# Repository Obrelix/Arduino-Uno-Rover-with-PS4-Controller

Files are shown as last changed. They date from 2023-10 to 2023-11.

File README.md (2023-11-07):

# Arduino Uno Rover with PS4 Controller

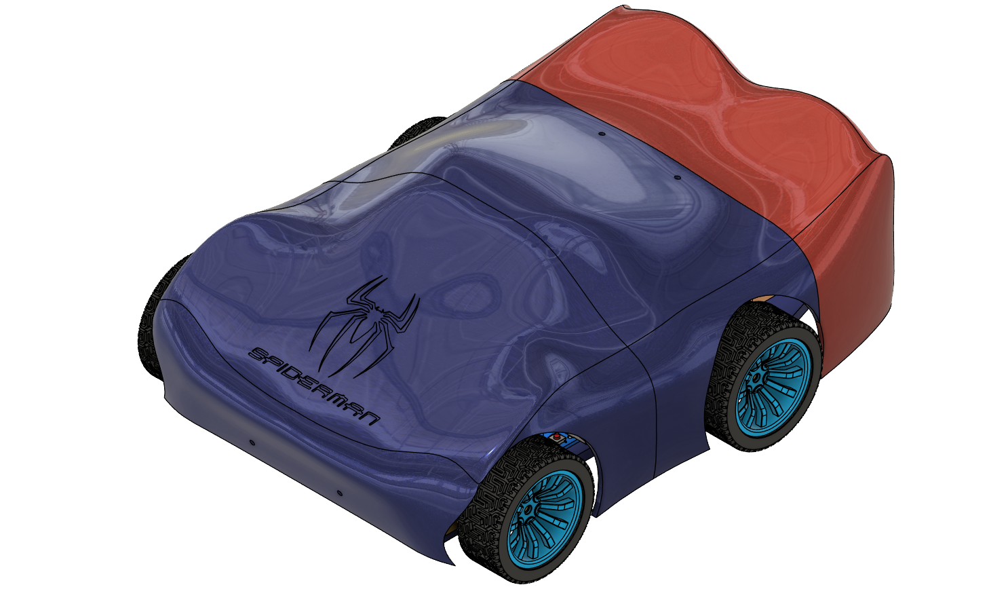
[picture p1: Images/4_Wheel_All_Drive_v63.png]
Rover Image


 Watch the video (https://youtu.be/d1QcqxO6J48)

This project showcases an Arduino Uno-based rover with a PS4 controller interface. The rover boasts four 65mm rubber wheels, driven by four JGB370-3530 brushed geared motors and controlled by dual L298N motor drivers. It runs on four 18650 Li-Ion batteries with a 4S BMS, ensuring ample power for all its electronic components for approximately 15-25 minutes on a single charge.

## Features

- **PS4 Controller Integration:** Control the rover via Bluetooth using a PS4 controller, enabled by the Arduino USB host shield and a Bluetooth dongle.  
- Support for various control **modes:**
  - **Car mode:** Control a car-like rover using joysticks.
  - **Car mode with triggers:** Control a car-like rover using triggers and the left joystick.
  - **Car mode with accelerometers:** Control a car-like rover using triggers for throttle and the accelerometer for steering.
  - **Funky car mode:** Control a unique car-like rover using the accelerometer for both throttle and steering.
  - **Tank mode:** Control a tank-like robot with separate control for each side using joysticks.
- **Turbo mode:** Activate turbo mode for max speed.
- **Speed mode:** Adjust the robot's speed on the fly. (doesn't apply to the turbo mode)
- **LED and Rumble feedback:** Indicate the current control mode and turbo mode using LED and rumble feedback on the PS4 controller.
- **3D-Printed Chassis:** The project includes 3D-printed chassis and shell models, designed with Fusion 360. These models are conveniently divided into parts for easier printing and assembly.

## Getting Started

To build and operate this project, follow these steps:

1. Assemble the rover chassis and shell using the 3D-printed parts provided in the [3D_Models](3D_Models/Printed_Parts) directory.

2. Connect the motors to the L298N motor drivers.

3. Ensure that the L298N motor drivers receive the correct power supply: raw voltage from the 4S BMS (>12V) and additional 5V voltage from a dc-to-dc step-down buck converter.

4. Set up the Arduino Uno with the required libraries and connect the Arduino USB host shield and Bluetooth dongle.

5. Upload the provided [Arduino sketch](AWD_PS4_RC/AWD_PS4_RC.ino) to the Arduino Uno.

6. Confirm that the Arduino Uno is powered with 12V from an individual dc-to-dc step-down buck converter.
   
7. Pair your PS4 controller with the Bluetooth dongle.
   
8. Power on the rover and start controlling it with your PS4 controller.   

## Usage

1. Control Modes:
   - Press the "Options" OR "Share" button to cycle through different control modes.
   - Control the robot based on the selected mode using the PS4 controller's buttons, joysticks, and triggers.

2. Turbo Mode:
   - Activate turbo mode by pressing specific button sequences on the controller (e.g., L1 + R1 + Triangle + Left).
   - Turbo mode increases the robot's speed.

3. Speed Mode:
   - Adjust the robot's speed by pressing the "Up" and "Down" buttons on the controller.

4. LED Feedback:
   - The LED on the PS4 controller provides feedback on the current control mode and turbo mode status.
     
## License

This project is licensed under the GNU GENERAL PUBLIC LICENSE - see the [LICENSE](https://github.com/Obrelix/Arduino-Uno-Rover-with-PS4-Controller/blob/main/LICENSE) file for details.

## Acknowledgments

- This project owes its existence to the contributions of the open-source Arduino community and the PS4BT library for Arduino.

- Special thanks to my collaborators, Kostas Vrailas and Thomas Vasiliou, who joined forces to create this project as a delightful gift for Kostas's young son.

Feel free to contribute, enhance, or customize this project as needed. If you have questions or feedback, please open an issue or get in touch with us.

Happy roving! 🚀

## Images

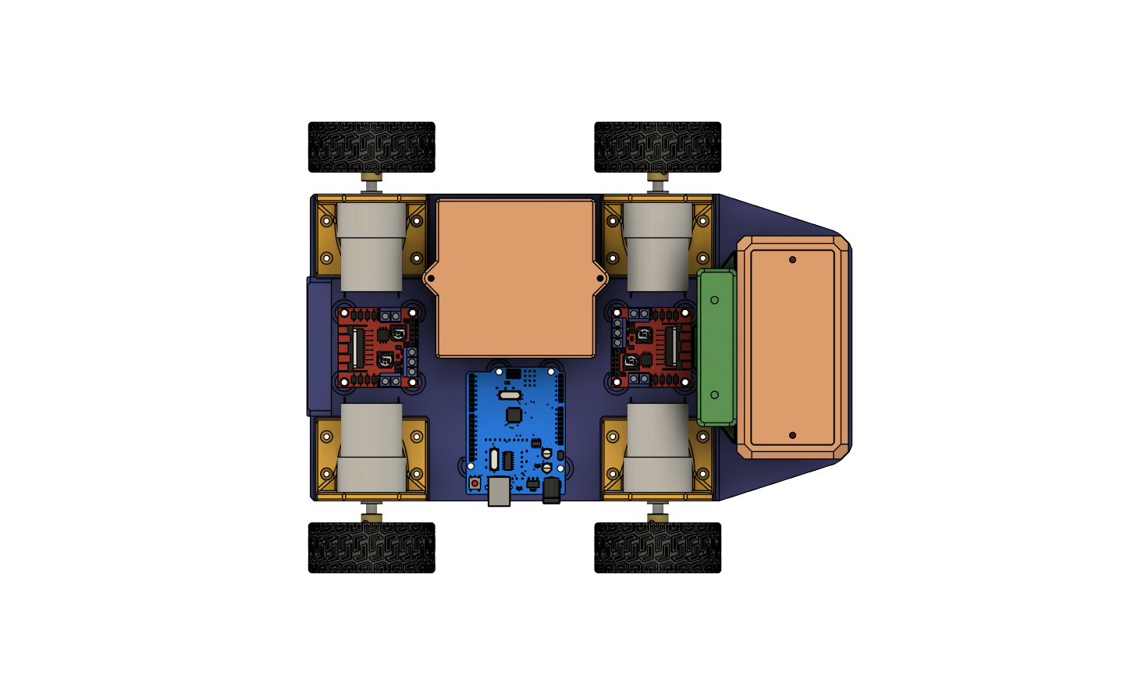
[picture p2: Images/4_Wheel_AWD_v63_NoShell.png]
Rover Image

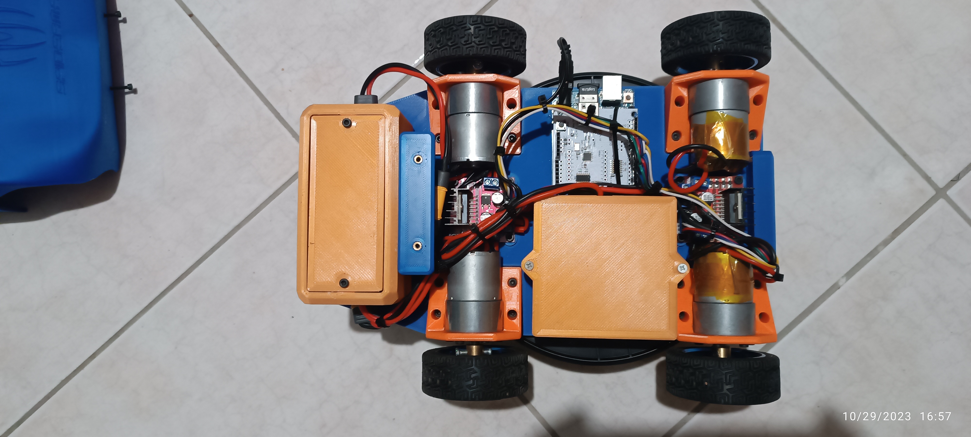
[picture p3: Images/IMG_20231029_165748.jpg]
Rover Image

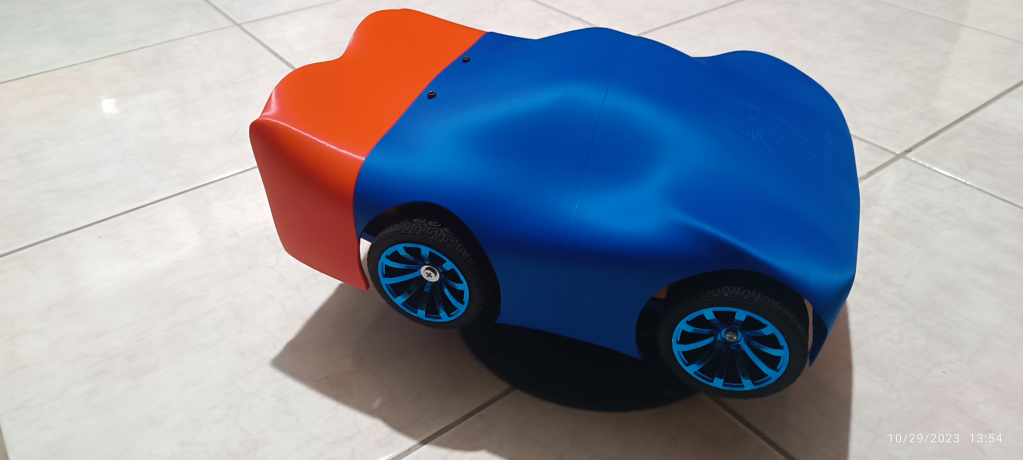
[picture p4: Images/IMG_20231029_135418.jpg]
Rover Image

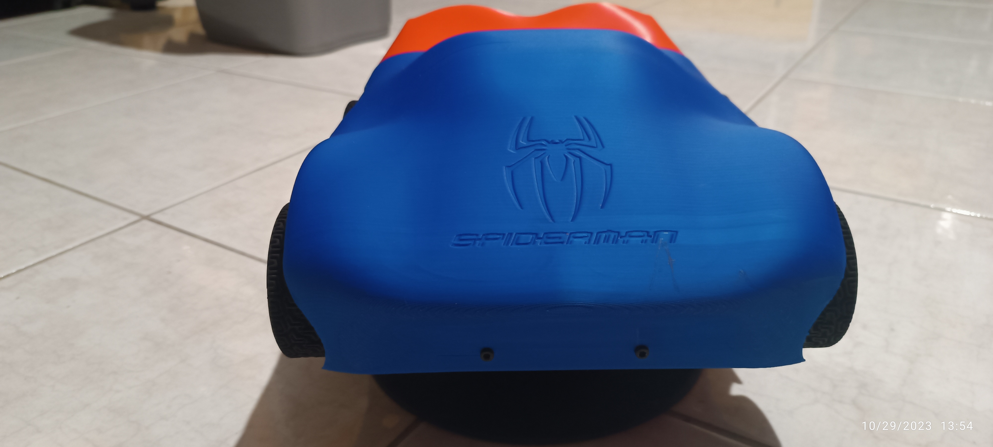
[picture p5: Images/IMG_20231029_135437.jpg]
Rover Image

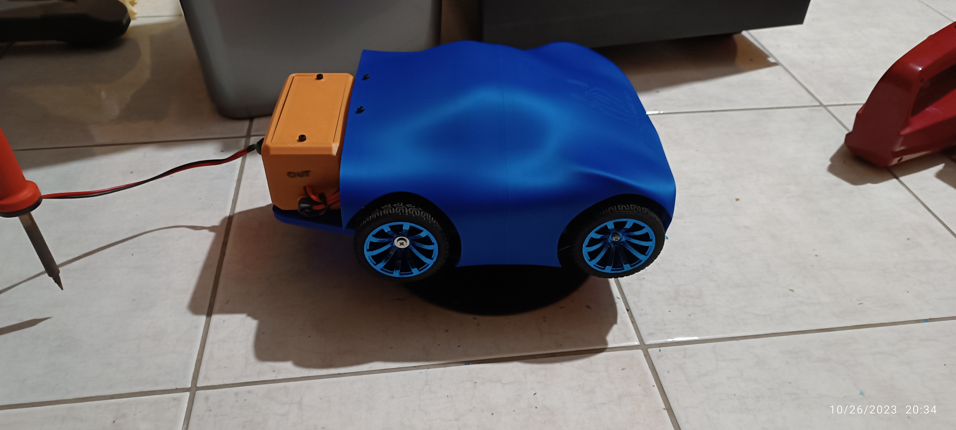
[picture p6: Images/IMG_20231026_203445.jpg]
Rover Image


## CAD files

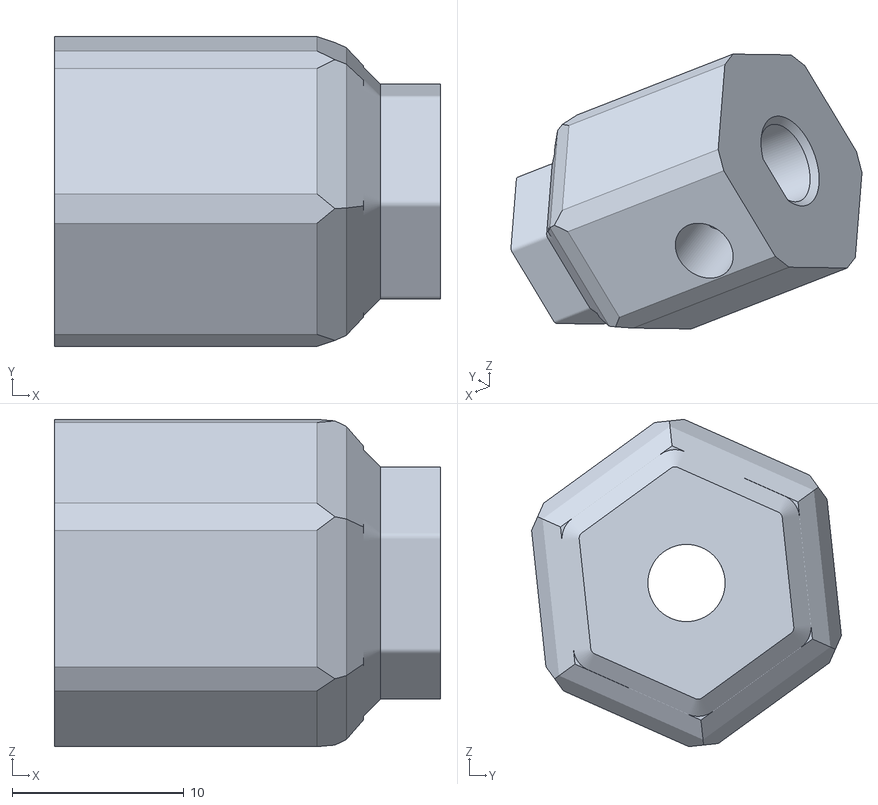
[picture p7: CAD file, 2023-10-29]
3D_Models/Printed_Parts/Wheel Adaptor x 4.stl
22.5 x 18.1 x 19.1

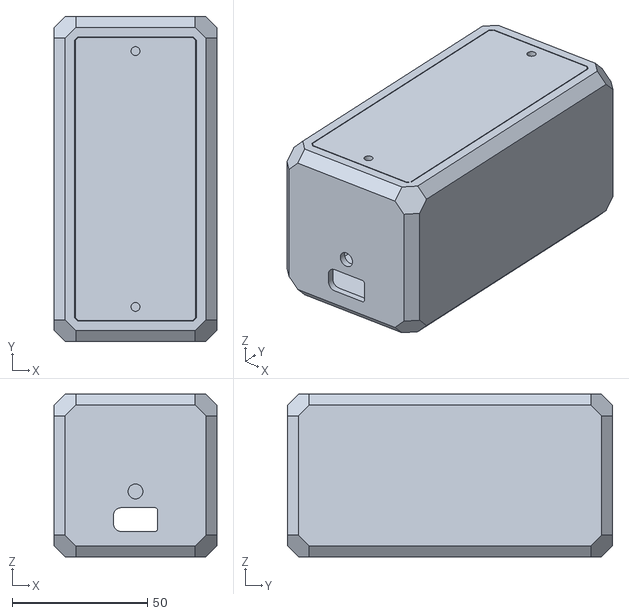
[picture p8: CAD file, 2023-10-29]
3D_Models/Printed_Parts/Power Box v4.stl
60.0 x 120.0 x 60.0

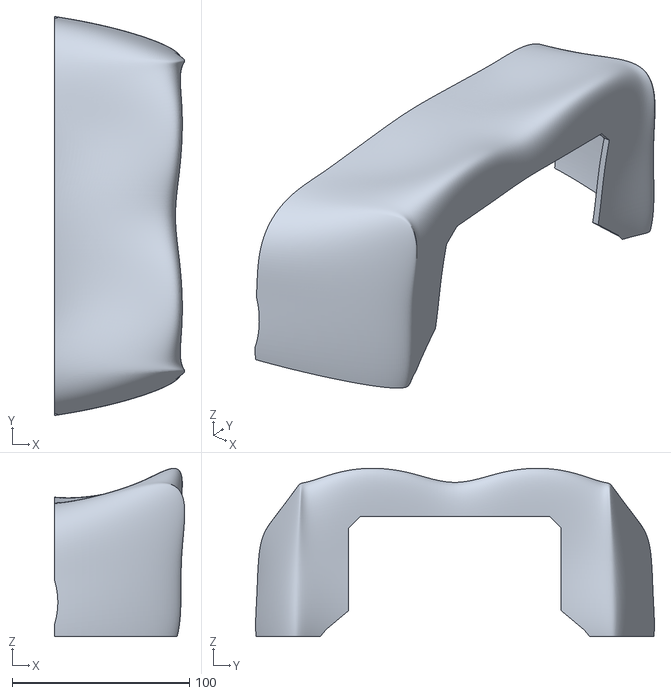
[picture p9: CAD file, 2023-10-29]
3D_Models/Printed_Parts/Shell Back.stl
73.6 x 225.1 x 95.0

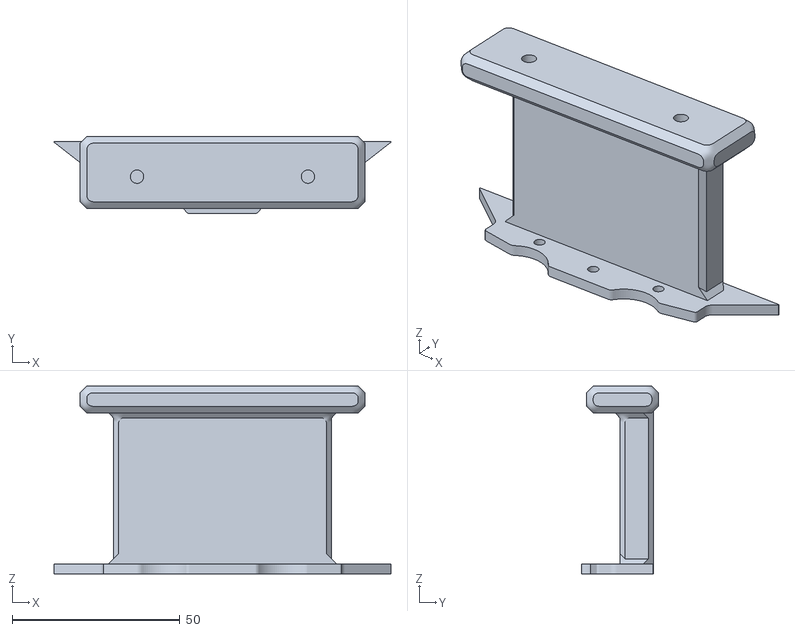
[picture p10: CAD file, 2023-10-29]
3D_Models/Printed_Parts/Rear Joint.stl
100.6 x 23.0 x 56.0

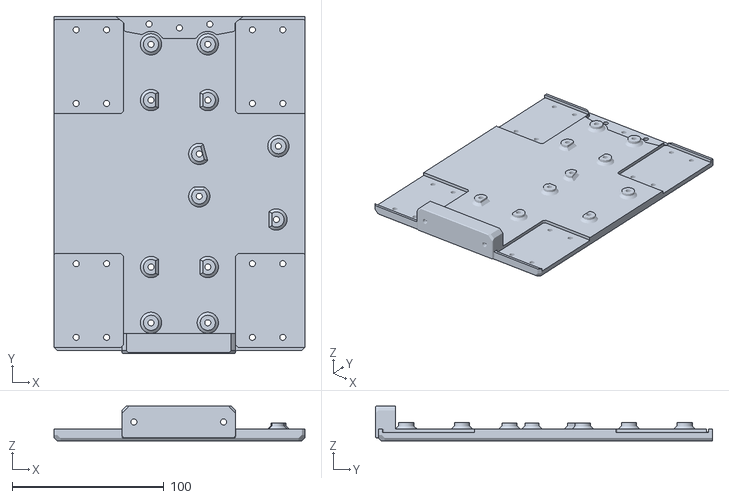
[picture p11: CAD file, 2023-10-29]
3D_Models/Printed_Parts/Base Plate.stl
165.0 x 221.9 x 23.0

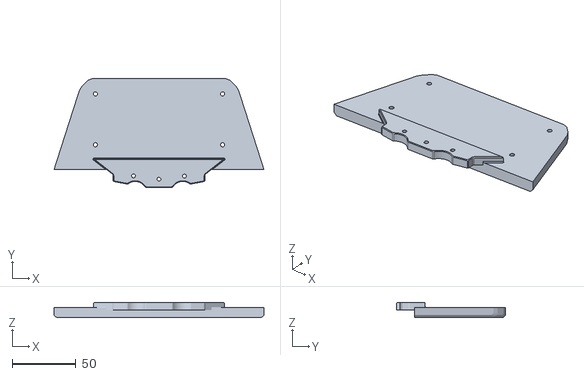
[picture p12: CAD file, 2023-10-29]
3D_Models/Printed_Parts/PowerBox Plate.stl
165.0 x 85.5 x 12.0

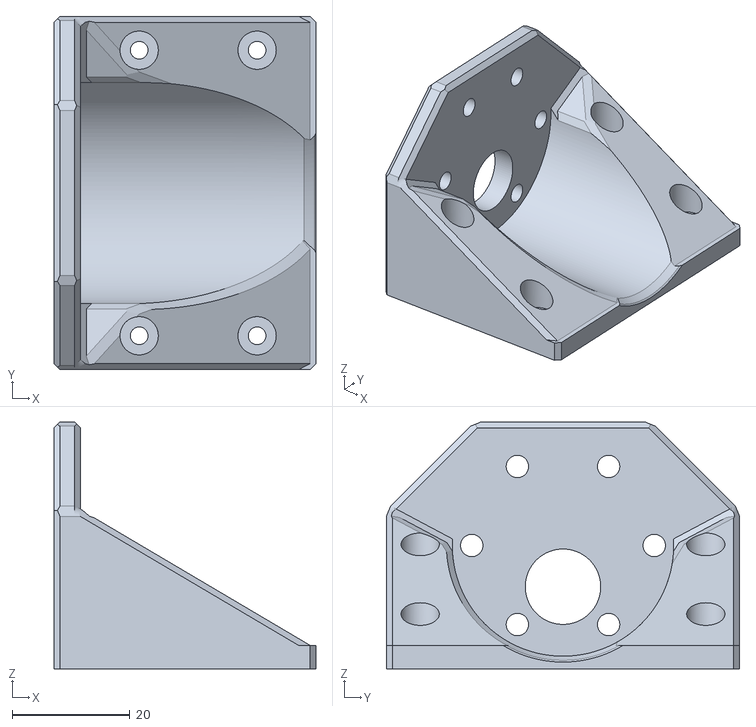
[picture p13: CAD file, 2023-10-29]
3D_Models/Printed_Parts/Motor Mount x 4.stl
44.5 x 60.0 x 41.9

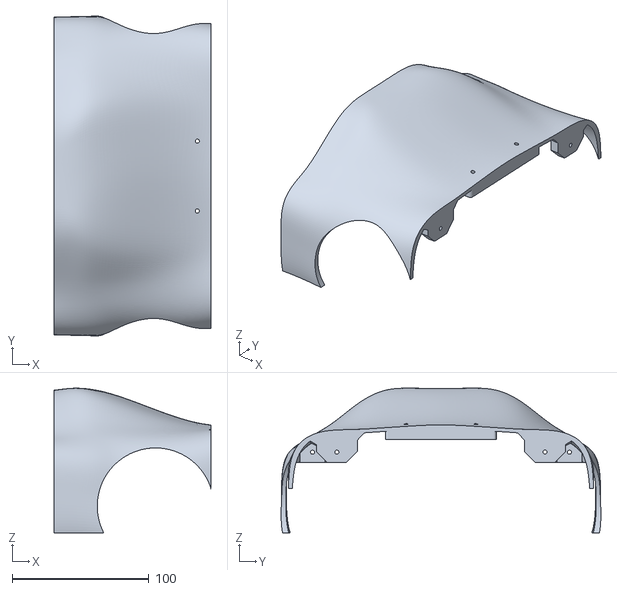
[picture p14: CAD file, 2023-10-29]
3D_Models/Printed_Parts/Shell Front Back.stl
114.6 x 233.5 x 105.6

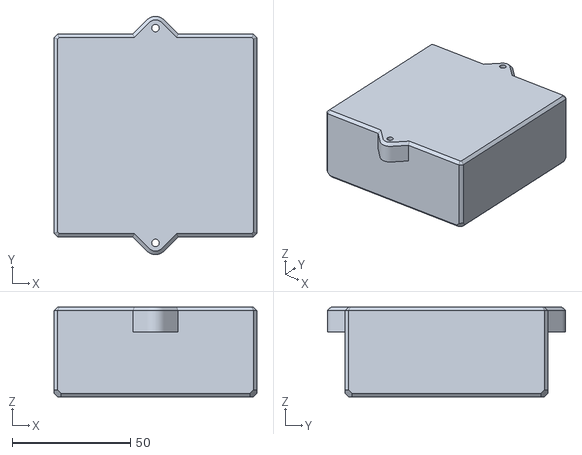
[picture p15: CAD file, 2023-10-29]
3D_Models/Printed_Parts/Baterry Box v3.stl
86.0 x 101.0 x 38.0

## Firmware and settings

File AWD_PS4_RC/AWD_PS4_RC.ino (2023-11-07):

// Include the necessary libraries
#include <PS4BT.h>
#include <usbhub.h>
#include <SPI.h>

// Define constant values
#define PWM_MIN 30             // minimum value for PWM (> 0)
#define PWM_MAX 254            // maximum value for PWM Turbo mode
#define PWM_SLOW 100           // maximum value for PWM Normal mode
#define PWM_BOOST 5            // maximum value for PWM Normal mode
#define PWM_STEERING_BOOST 60  // Normal Mode PWM Accumulator for steering wheels

// Define debug flags (comment out as needed)
// #define DEBUG_MOTORS
// #define DEBUG_CONTROLLER
// #define DEBUG_DRIVE_DATA

// Define structures to hold data
struct Motor_Data {  // ... (motor data fields)
  bool motor_left_update;
  bool motor_left_stop;
  uint8_t motor_left_dir;
  uint8_t motor_left_pwm;
  uint8_t motor_left_stop_count;
  bool motor_right_update;
  bool motor_right_stop;
  uint8_t motor_right_dir;
  uint8_t motor_right_pwm;
  uint8_t motor_right_stop_count;
};

struct PS4_Controller_Data {  // ... (controller data fields)
  uint8_t joy_right_PotX;
  uint8_t joy_right_PotY;
  uint8_t joy_left_PotX;
  uint8_t joy_left_PotY;
  uint8_t L2;
  uint8_t R2;
  bool joy_right_Btn;
  bool joy_left_Btn;
  bool L1;
  bool R1;
  bool share_Btn;
  bool options_Btn;
  bool PS_Btn;
  bool triangle_Btn;
  bool square_Btn;
  bool circle_Btn;
  bool cross_Btn;
  bool up_Btn;
  bool down_Btn;
  bool left_Btn;
  bool right_Btn;
  bool show_connected_msg;
  bool show_disconnected_msg;
  // int16_t gyro_x;
  // int16_t gyro_y;
  // int16_t gyro_z;
  int16_t acc_x;
  int16_t acc_y;
  // int16_t acc_z;
};

struct Turbo_Sequense_Data {  // ... (turbo data fields)
  bool ENABLED;
  bool RESETED;
  bool L1;
  bool R1;
  bool triangle_Btn;
  bool left_Btn;
  unsigned long last_pressed_millis;
};

struct Rumble_Data {
  bool ENABLED;
  uint16_t delay;
  unsigned long last_enabled_millis;
};

struct Drive_Data {        // ... (drive data fields)
  uint8_t turn_direction;  // 1 --> ternLeft, 2 --> turnRight, 0 --> no turn
  uint8_t steering_value;
  uint8_t drive_direction;  // 1 --> drive forward, 2 --> drive backward, 0 --> stop
  uint8_t throttle_value;
};

struct Color {
  uint8_t r;
  uint8_t g;
  uint8_t b;
};

// create USB and and Bluetooth Dongle instances
USB Usb;
BTD Btd(&Usb);
PS4BT PS4(&Btd, PAIR);

// Define global variables
Motor_Data motor_data;
Motor_Data prev_motor_data;
PS4_Controller_Data controller_data;
Turbo_Sequense_Data turbo_data;
Drive_Data drive_data;
Rumble_Data rumble_data;
Color tank_color;
Color car_color;
Color car_trigger_color;
Color car_accel_color;
Color funky_car_color;
Color turbo_color;
Color current_color;
int16_t trigger_throttle_value = 0;
unsigned long current_millis = 0;
const uint8_t turbo_sequence_threshold = 300;
const uint8_t mode_count = 4;
const uint8_t motor_count = 2;                  // Number of controlling motors
const uint8_t pwm_pins[2] = { 6, 5 };           // pins 6 and 5  [980 Hz PWM] of the arduino uno controlling speed with pwm signal with pins (ENA, ENB) of the L298n drive
const uint8_t forward_dir_pins[2] = { 8, 3 };   // pins 8 and 3 of the arduino uno enable the forward movement pins (IN1,IN3) of the L298n drive
const uint8_t backward_dir_pins[2] = { 7, 4 };  // pins 7 and 4 of the arduino uno enable the backward movement pins (IN2,IN4) of the L298n drive
int8_t mode = 0;                                //   0 -> car, 1 -> car trigger, 2 -> car accel, 3 -> funky car 4 -> tank
int8_t speed_mode = 0;
uint8_t pwm_max = 0;
uint8_t steering_pwm_min = 0;
uint8_t steering_pwm_max = 0;
uint8_t steering_pwm = 0;  // in case of steering  the one pair of wheels should run in the oposite direction of the rover's moving direction with slower speed in order to simulate smooth turning   ( this is not applied on the tank mode)
uint8_t throttle_steering_pwm = 0;
uint8_t throttle_pwm = 0;


void setup() {
  Serial.begin(115200);
  if (Usb.Init() == -1) {
    Serial.print(F("\r\nOSC did not start"));
    while (1)
      ;  // Halt
  }
  Serial.print(F("\r\nPS4 Bluetooth Library Started"));
  for (int motor = 0; motor < motor_count; motor++) {  // Set all the motor control pins to outputs
    pinMode(pwm_pins[motor], OUTPUT);
    pinMode(forward_dir_pins[motor], OUTPUT);
    pinMode(backward_dir_pins[motor], OUTPUT);
  }
  set_default_values();  // Initializes default values for various variables and configuration settings
}

void loop() {
  current_millis = millis();
  Usb.Task();
  if (!check_controller_connection()) return;  // Check if the PS4 controller is connected and handles connection-related messages.
  get_controller_values();                     // Retrieve various controller input values from the PS4 controller.
  if (check_abort()) return;                   // handles aborting the operation if the PS button is pressed on the controller.
  check_turbo_mode();                          // Check for turbo mode and adjust PWM values accordingly.
  check_speed_mode();                          // Check for speed mode and adjust PWM values accordingly.
  set_drive_mode();                            // Set the drive mode based on the controller's button presses.
  run_motors();                                // Control the motors based on the motor data, including direction and PWM values.
  print_debug_data();                          // Depending on the debug flags, this function prints debug data related to motors and controller inputs to the serial console
  check_kill_rumble();
}

void run_motors() {  // This function controls the motors based on the motor data, including direction and PWM values.
  if (motor_data.motor_left_stop && motor_data.motor_left_update) {
    analogWrite(pwm_pins[0], 254);
    digitalWrite(forward_dir_pins[0], 0);
    digitalWrite(backward_dir_pins[0], 0);
  } else if (motor_data.motor_left_update) {
    analogWrite(pwm_pins[0], motor_data.motor_left_pwm);
    digitalWrite(forward_dir_pins[0], motor_data.motor_left_dir == 1);
    digitalWrite(backward_dir_pins[0], motor_data.motor_left_dir != 1);
  }
  if (motor_data.motor_right_stop && motor_data.motor_right_update) {
    analogWrite(pwm_pins[1], 254);
    digitalWrite(forward_dir_pins[1], 0);
    digitalWrite(backward_dir_pins[1], 0);
  } else if (motor_data.motor_right_update) {
    analogWrite(pwm_pins[1], motor_data.motor_right_pwm);
    digitalWrite(forward_dir_pins[1], motor_data.motor_right_dir == 1);
    digitalWrite(backward_dir_pins[1], motor_data.motor_right_dir != 1);
  }
}

void get_controller_values() {  // This function retrieves various controller input values like joystick positions, button presses, and sensor data from the PS4 controller using the PS4BT library.
  controller_data.joy_left_PotY = PS4.getAnalogHat(LeftHatY);
  controller_data.joy_left_PotX = PS4.getAnalogHat(LeftHatX);
  controller_data.joy_right_PotY = PS4.getAnalogHat(RightHatY);
  // controller_data.joy_right_PotX = PS4.getAnalogHat(RightHatX);
  // controller_data.joy_right_Btn = PS4.getButtonClick(R3);
  // controller_data.joy_left_Btn = PS4.getButtonClick(L3);
  controller_data.L1 = PS4.getButtonClick(L1);
  controller_data.R1 = PS4.getButtonClick(R1);
  controller_data.L2 = PS4.getAnalogButton(L2);
  controller_data.R2 = PS4.getAnalogButton(R2);
  controller_data.options_Btn = PS4.getButtonClick(OPTIONS);
  controller_data.share_Btn = PS4.getButtonClick(SHARE);
  controller_data.PS_Btn = PS4.getButtonClick(PS);
  // controller_data.square_Btn = PS4.getButtonClick(SQUARE);
  controller_data.triangle_Btn = PS4.getButtonClick(TRIANGLE);
  // controller_data.circle_Btn = PS4.getButtonClick(CIRCLE);
  // controller_data.cross_Btn = PS4.getButtonClick(CROSS);
  controller_data.up_Btn = PS4.getButtonClick(UP);
  controller_data.down_Btn = PS4.getButtonClick(DOWN);
  controller_data.left_Btn = PS4.getButtonClick(LEFT);
  controller_data.right_Btn = PS4.getButtonClick(RIGHT);
  if (mode == 2 || mode == 3) {
    // controller_data.gyro_x = PS4.getSensor(gX);
    // controller_data.gyro_y = PS4.getSensor(gY);
    // controller_data.gyro_z = PS4.getSensor(gZ);
    controller_data.acc_x = PS4.getSensor(aX);
    controller_data.acc_y = PS4.getSensor(aY);
    // controller_data.acc_z = PS4.getSensor(aZ);
  } else {
    controller_data.acc_x = 0;
    controller_data.acc_y = 0;
  }
}

//R1+L1+TRIANGLE+LEFT
void check_turbo_mode() {  // This function checks for a specific button sequence on the controller to activate or deactivate turbo mode, adjusting PWM values accordingly.
  // Check if any of the specified buttons are pressed on the controller.
  if (controller_data.triangle_Btn || controller_data.left_Btn || controller_data.L1 || controller_data.R1) {
    turbo_data.RESETED = 1;                           // Set the turbo mode as reset.
    turbo_data.last_pressed_millis = current_millis;  // Record the current time in milliseconds.
    if (!turbo_data.L1)                               // Update the turbo_data flags based on the controller buttons.
      turbo_data.L1 = controller_data.L1;
    if (!turbo_data.R1)
      turbo_data.R1 = controller_data.R1;
    if (!turbo_data.triangle_Btn)
      turbo_data.triangle_Btn = controller_data.triangle_Btn;
    if (!turbo_data.left_Btn)
      turbo_data.left_Btn = controller_data.left_Btn;
    if (turbo_data.L1 && turbo_data.R1 && turbo_data.triangle_Btn && turbo_data.left_Btn) {  // Check if a specific button sequence (L1, R1, Triangle, Down) is pressed simultaneously.
      turbo_data.ENABLED = !turbo_data.ENABLED;                                              // Toggle the turbo mode (ENABLED) flag.
      Serial.print(F("\r\nTURBO MODE: "));                                                   // Print the status of the turbo mode to the serial monitor.
      Serial.print(turbo_data.ENABLED);
      if (turbo_data.ENABLED) {
        PS4.setLedFlash(10, 5);  // Set it to blink rapidly
        set_rumble_on(254, 2000);
      } else {
        PS4.setLedFlash(0, 0);  // Turn off blinking
        PS4.setRumbleOn(0, 0);
      }
      // Adjust PWM values based on the turbo mode status.
      pwm_max = turbo_data.ENABLED ? PWM_MAX : PWM_SLOW;
      steering_pwm_min = !turbo_data.ENABLED ? PWM_MIN + PWM_STEERING_BOOST : PWM_MIN;
      steering_pwm_max = !turbo_data.ENABLED ? pwm_max + PWM_STEERING_BOOST : PWM_MAX;
      set_controller_color();  // Update the controller color based on the turbo mode status.
    }
  }
  // Check if a certain amount of time has passed since the last button press and if turbo mode was reset and reset the turbo_data flags.
  if (current_millis - turbo_data.last_pressed_millis > turbo_sequence_threshold && turbo_data.RESETED) {
    turbo_data.L1 = 0;
    turbo_data.R1 = 0;
    turbo_data.triangle_Btn = 0;
    turbo_data.left_Btn = 0;
    turbo_data.RESETED = 0;
    set_controller_color();
  }
}

void check_speed_mode() {
  if (turbo_data.ENABLED) return;  // If Turbo Mode is enabled, exit the function.
  if (controller_data.down_Btn || controller_data.up_Btn) {
    speed_mode += controller_data.up_Btn ? 1 : -1;
    if (speed_mode >= 6) {  
      speed_mode = 6;
      set_rumble_on(254, 1000); // Enable rumble feedback and set it to a high intensity.
    } else if (speed_mode <= 0) {
      speed_mode = 0;
      set_rumble_on(150, 1000); // Enable rumble feedback and set it to a medium intensity.
    }
    pwm_max = PWM_SLOW;
    pwm_max += speed_mode * PWM_BOOST;
    set_controller_color(); // Update the LED color on the controller to reflect the speed mode.
    Serial.print(F("\r\nSPEED MODE: "));  // Print the status of the speed mode to the serial monitor.
    Serial.print(speed_mode);
  }
}

void check_kill_rumble() {
  if (rumble_data.ENABLED && current_millis - rumble_data.last_enabled_millis > rumble_data.delay) {
    rumble_data.ENABLED = false; // Disable rumble feedback.
    PS4.setRumbleOn(0, 0);// Turn off rumble.
  }
}

void set_rumble_on(uint8_t rumble_value, uint16_t delay) {
  PS4.setRumbleOn(0, rumble_value); // Enable rumble feedback with the specified intensity.
  rumble_data.ENABLED = true; // Mark rumble feedback as enabled.
  rumble_data.last_enabled_millis = current_millis; // Record the current time.
  rumble_data.delay = delay; // Set the delay duration for rumble feedback.
}

bool check_controller_connection() {  // This function checks if the PS4 controller is connected and handles connection-related messages.
  // if not connected do nothing
  if (!PS4.connected()) {
    if (controller_data.show_disconnected_msg)
      Serial.print(F("\r\nPS4 is not connected. Waiting ..."));
    controller_data.show_disconnected_msg = 0;
    controller_data.show_connected_msg = 1;
    delay(60);
    return 0;
  } else if (controller_data.show_connected_msg) {
    controller_data.show_connected_msg = 0;
    controller_data.show_disconnected_msg = 1;
    Serial.print(F("\r\nPS4 connected."));
    print_mode();
    set_controller_color();
  }
  return 1;
}

bool check_abort() {  // This function handles aborting the operation if the PS button is pressed on the controller.
  if (controller_data.PS_Btn) {
    Serial.print(F("\r\nABORT!!!"));
    // PS4.disconnect();
    motor_data.motor_left_stop = 1;
    motor_data.motor_right_stop = 1;
    run_motors();
    return 1;
  }
  return 0;
}

// This function sets the motor control mode for a tank-style robot based on joystick input.
void set_tank_mode() {
  if (controller_data.joy_left_PotY > 140) {                                                     // Check the left joystick's vertical position to control the left motor.
    motor_data.motor_left_dir = 2;                                                               // Move the left motor backward
    motor_data.motor_left_pwm = map(controller_data.joy_left_PotY, 140, 254, PWM_MIN, pwm_max);  // Map joystick input to the left motor's PWM value.
    motor_data.motor_left_stop = 0;                                                              // Ensure the left motor is not stopped.
  } else if (controller_data.joy_left_PotY < 110) {
    motor_data.motor_left_dir = 1;                                                             // Move the left motor forward
    motor_data.motor_left_pwm = map(controller_data.joy_left_PotY, 110, 0, PWM_MIN, pwm_max);  // Map joystick input to the left motor's PWM value.
    motor_data.motor_left_stop = 0;                                                            // Ensure the left motor is not stopped.
  } else {                                                                                     // Stop the left motor.
    motor_data.motor_left_dir = 0;
    motor_data.motor_left_pwm = 0;
    motor_data.motor_left_stop = 1;  // Signal that the left motor is stopped.
  }

  if (controller_data.joy_right_PotY > 140) {                                                      // Check the right joystick's vertical position to control the right motor.
    motor_data.motor_right_dir = 2;                                                                // Move the right motor backward.
    motor_data.motor_right_pwm = map(controller_data.joy_right_PotY, 140, 254, PWM_MIN, pwm_max);  // Map joystick input to the right motor's PWM value.
    motor_data.motor_right_stop = 0;                                                               // Ensure the right motor is not stopped.
  } else if (controller_data.joy_right_PotY < 110) {
    motor_data.motor_right_dir = 1;                                                              // Move the right motor forward.
    motor_data.motor_right_pwm = map(controller_data.joy_right_PotY, 110, 0, PWM_MIN, pwm_max);  // Map joystick input to the right motor's PWM value.
    motor_data.motor_right_stop = 0;                                                             // Ensure the right motor is not stopped.
  } else {                                                                                       // Stop the right motor.
    motor_data.motor_right_dir = 0;
    motor_data.motor_right_pwm = 0;
    motor_data.motor_right_stop = 1;  // Signal that the right motor is stopped.
  }
  // If turbo mode is not enabled and the motors have opposite directions, boost the PWM values for easier turning.
  if (!turbo_data.ENABLED && motor_data.motor_right_dir != motor_data.motor_left_dir) {
    if (!motor_data.motor_right_stop)
      motor_data.motor_right_pwm = map(motor_data.motor_right_pwm, PWM_MIN, pwm_max, PWM_MIN + PWM_STEERING_BOOST, pwm_max + PWM_STEERING_BOOST);
    if (!motor_data.motor_left_stop)
      motor_data.motor_left_pwm = map(motor_data.motor_left_pwm, PWM_MIN, pwm_max, PWM_MIN + PWM_STEERING_BOOST, pwm_max + PWM_STEERING_BOOST);
  }
  // Determine if the motor control values have been updated.
  motor_data.motor_left_update = (prev_motor_data.motor_left_dir != motor_data.motor_left_dir || prev_motor_data.motor_left_pwm != motor_data.motor_left_pwm);
  motor_data.motor_right_update = (prev_motor_data.motor_right_dir != motor_data.motor_right_dir || prev_motor_data.motor_right_pwm != motor_data.motor_right_pwm);
}

void set_drive_mode() {  // This function sets the drive mode based on the controller's button presses. The drive mode determines how the motors respond to controller inputs.
  if (controller_data.options_Btn) {
    mode++;  // Increase the drive mode.
    if (mode > mode_count)
      mode = 0;
    speed_mode = 0;
  } else if (controller_data.share_Btn) {
    mode--;  // Decrease the drive mode.
    if (mode < 0)
      mode = mode_count;
  }
  if (controller_data.options_Btn || controller_data.share_Btn) {
    set_rumble_on(254, 600);
    PS4.setLedFlash(0, 0);  // Turn off blinking
    turbo_data.ENABLED = false;
    turbo_data.RESETED = 1;
    turbo_data.last_pressed_millis = current_millis;
    // RESET PWM values
    pwm_max = PWM_SLOW;
    steering_pwm_min = PWM_MIN + PWM_STEERING_BOOST;
    steering_pwm_max = PWM_SLOW + PWM_STEERING_BOOST;
    speed_mode = 0;
    set_controller_color(); // Update the LED color on the controller.
    print_mode(); // Print the current drive mode to the console.
  }
  prev_motor_data = motor_data;
  trigger_throttle_value = controller_data.R2 - controller_data.L2;
  switch (mode) {
    case 0:  // Car mode controlled with the joysticks
      set_direction_data(controller_data.joy_right_PotY, 0, 110, 254, 140);
      set_steering_data(controller_data.joy_left_PotX, 0, 105, 254, 145);
      set_motor_data();
      break;
    case 1:  // Car mode controlled with the R2,L2 triggers for throttle and the left joystick for steering.
      set_direction_data(trigger_throttle_value, -255, -10, 255, 10);
      set_steering_data(controller_data.joy_left_PotX, 0, 105, 254, 145);
      set_motor_data();
      break;
    case 2:  // Car mode controlled with the R2,L2 for throttle triggers and the accelerometer for steering.
      set_direction_data(trigger_throttle_value, -255, -10, 255, 10);
      set_steering_data(controller_data.acc_x, -8500, -2000, 8500, 2000);
      set_motor_data();
      break;
    case 3:  // Car mode controlled only with the accelerometer
      set_direction_data(controller_data.acc_y, -8500, -2000, 8500, 2000);
      set_steering_data(controller_data.acc_x, -8500, -2000, 8500, 2000);
      set_motor_data();
      break;
    case 4:  // Tank mode controlled with the joysticks
      set_tank_mode();
      break;
    default:
      break;
  }
}

// This function sets the drive direction and throttle value based on the input throttle parameter, considering the specified minimum and maximum values with offsets.
void set_direction_data(int16_t throttle_param, int16_t minVal, int16_t offsetMinVal, int16_t maxVal, int16_t offsetMaxVal) {
  if (throttle_param > offsetMaxVal) {
    drive_data.drive_direction = mode == 0 ? 2 : 1;
    drive_data.throttle_value = map(throttle_param, offsetMaxVal, maxVal, 0, 100);
  } else if (throttle_param < offsetMinVal) {
    drive_data.drive_direction = mode == 0 ? 1 : 2;
    drive_data.throttle_value = map(throttle_param, offsetMinVal, minVal, 0, 100);
  } else {
    drive_data.drive_direction = 0;
    drive_data.throttle_value = 0;
  }
}

// This function sets the turn direction and steering value based on the input steering parameter, considering the specified minimum and maximum values with offsets.
void set_steering_data(int16_t steering_param, int16_t minVal, int16_t offsetMinVal, int16_t maxVal, int16_t offsetMaxVal) {
  if (steering_param > offsetMaxVal) {
    drive_data.turn_direction = mode == 3 || mode == 2 ? 2 : 1;
    drive_data.steering_value = map(steering_param, offsetMaxVal, maxVal, 0, 100);
  } else if (steering_param < offsetMinVal) {
    drive_data.turn_direction = mode == 3 || mode == 2 ? 1 : 2;
    drive_data.steering_value = map(steering_param, offsetMinVal, minVal, 0, 100);
  } else {
    drive_data.turn_direction = 0;
    drive_data.steering_value = 0;
  }
}
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

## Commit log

2023-10-29 3D models added for the printed parts
    [Base Plate.stl, Baterry Box v3.stl, Motor Mount x 4.stl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]
2023-11-05 Steering updated
